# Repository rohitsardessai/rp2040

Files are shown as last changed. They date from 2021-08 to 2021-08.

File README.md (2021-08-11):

# RP2040 Breakout board

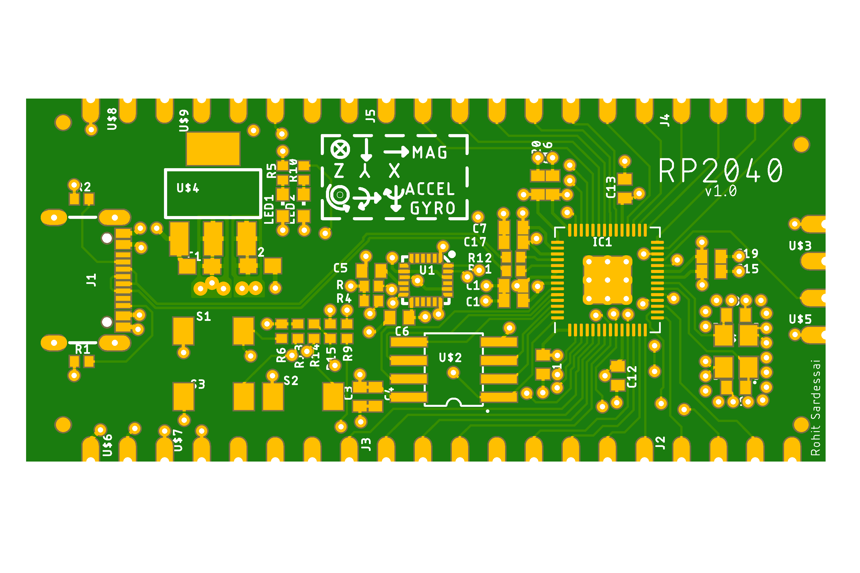
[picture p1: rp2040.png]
Board Preview


Breakout board for the RP2040 microcontroller with minimal circuitry.
The repository contains Eagle board files and libraries.

Features:
- 4 Layer board stackup (sig-gnd-pwr-sig)
- 55mm x 25mm
- RP2040
- USB-C interface (90 Ohm differential impedance)
- MPU9250 9 DoF IMU
- User button and LED
- Castellated pads

This board was made by referring to Philip Salmony's wonderful [YouTube channel](https://www.youtube.com/c/PhilS94/videos) . I highly recommend it.
Sparkfun's open source designs also helped a lot.

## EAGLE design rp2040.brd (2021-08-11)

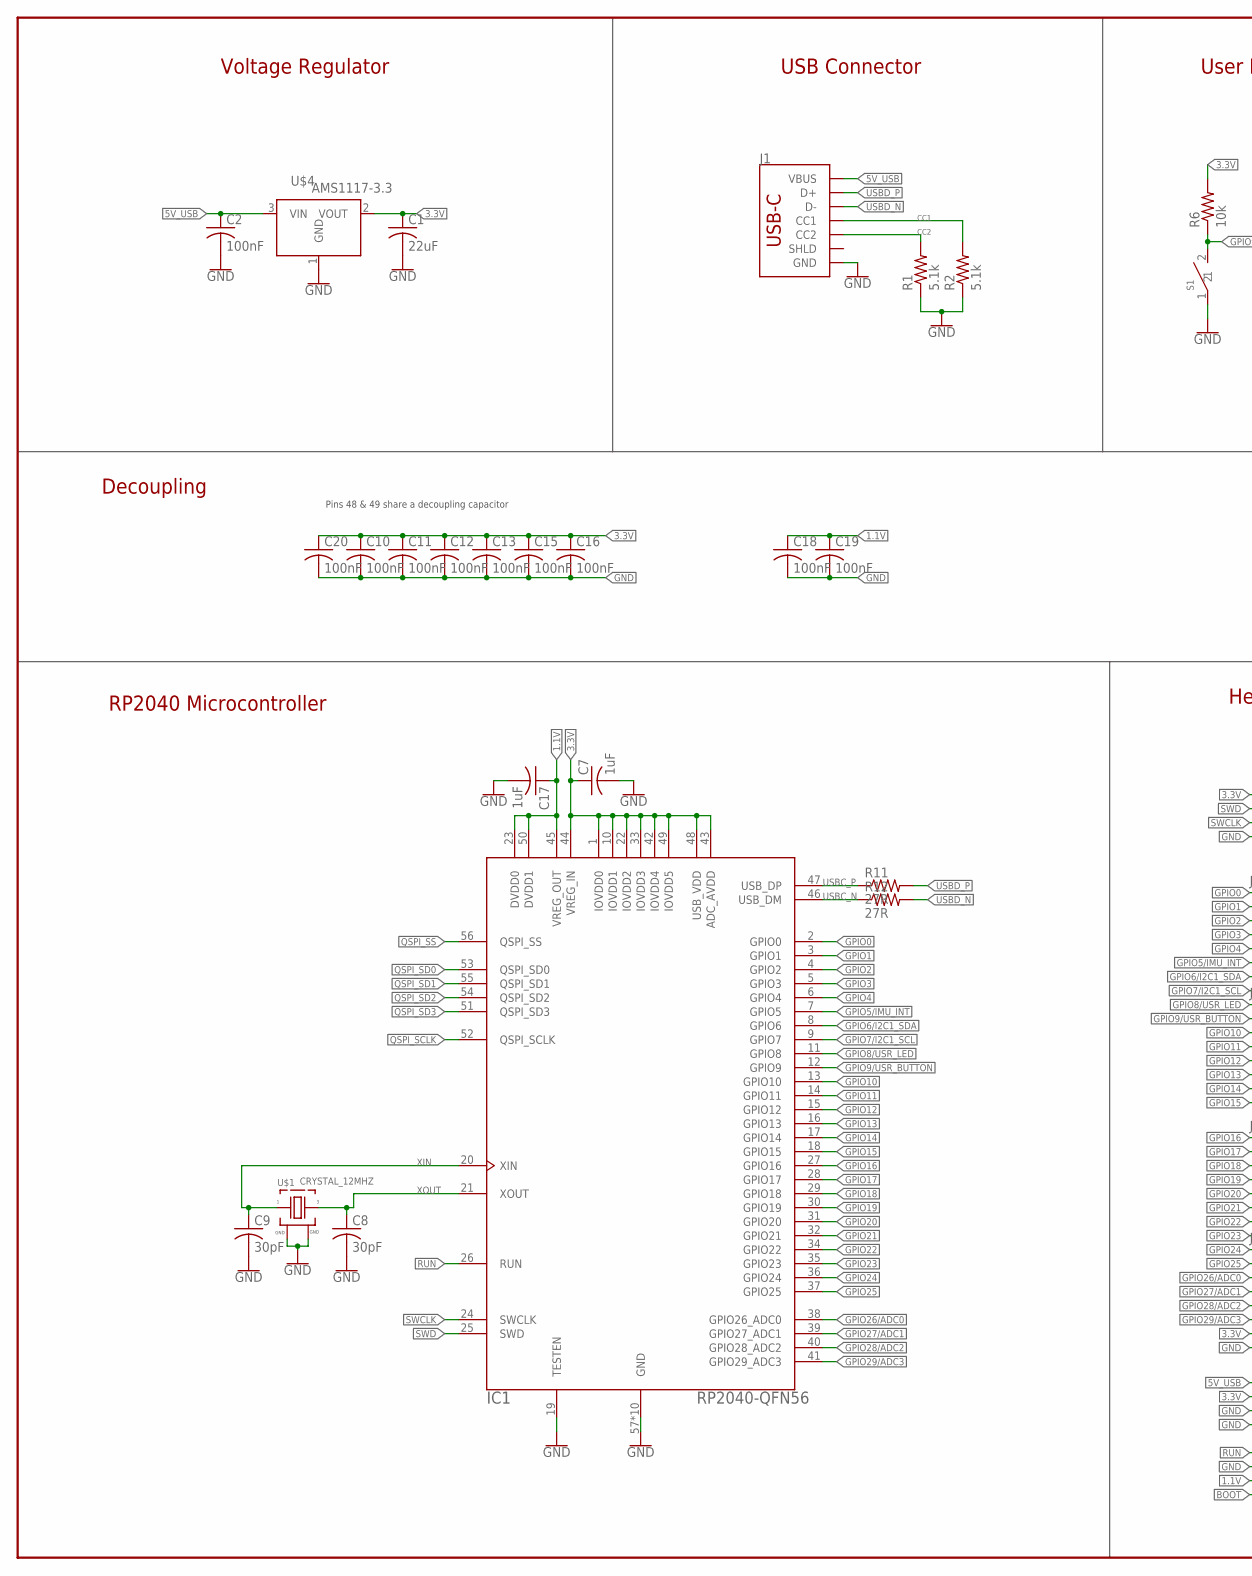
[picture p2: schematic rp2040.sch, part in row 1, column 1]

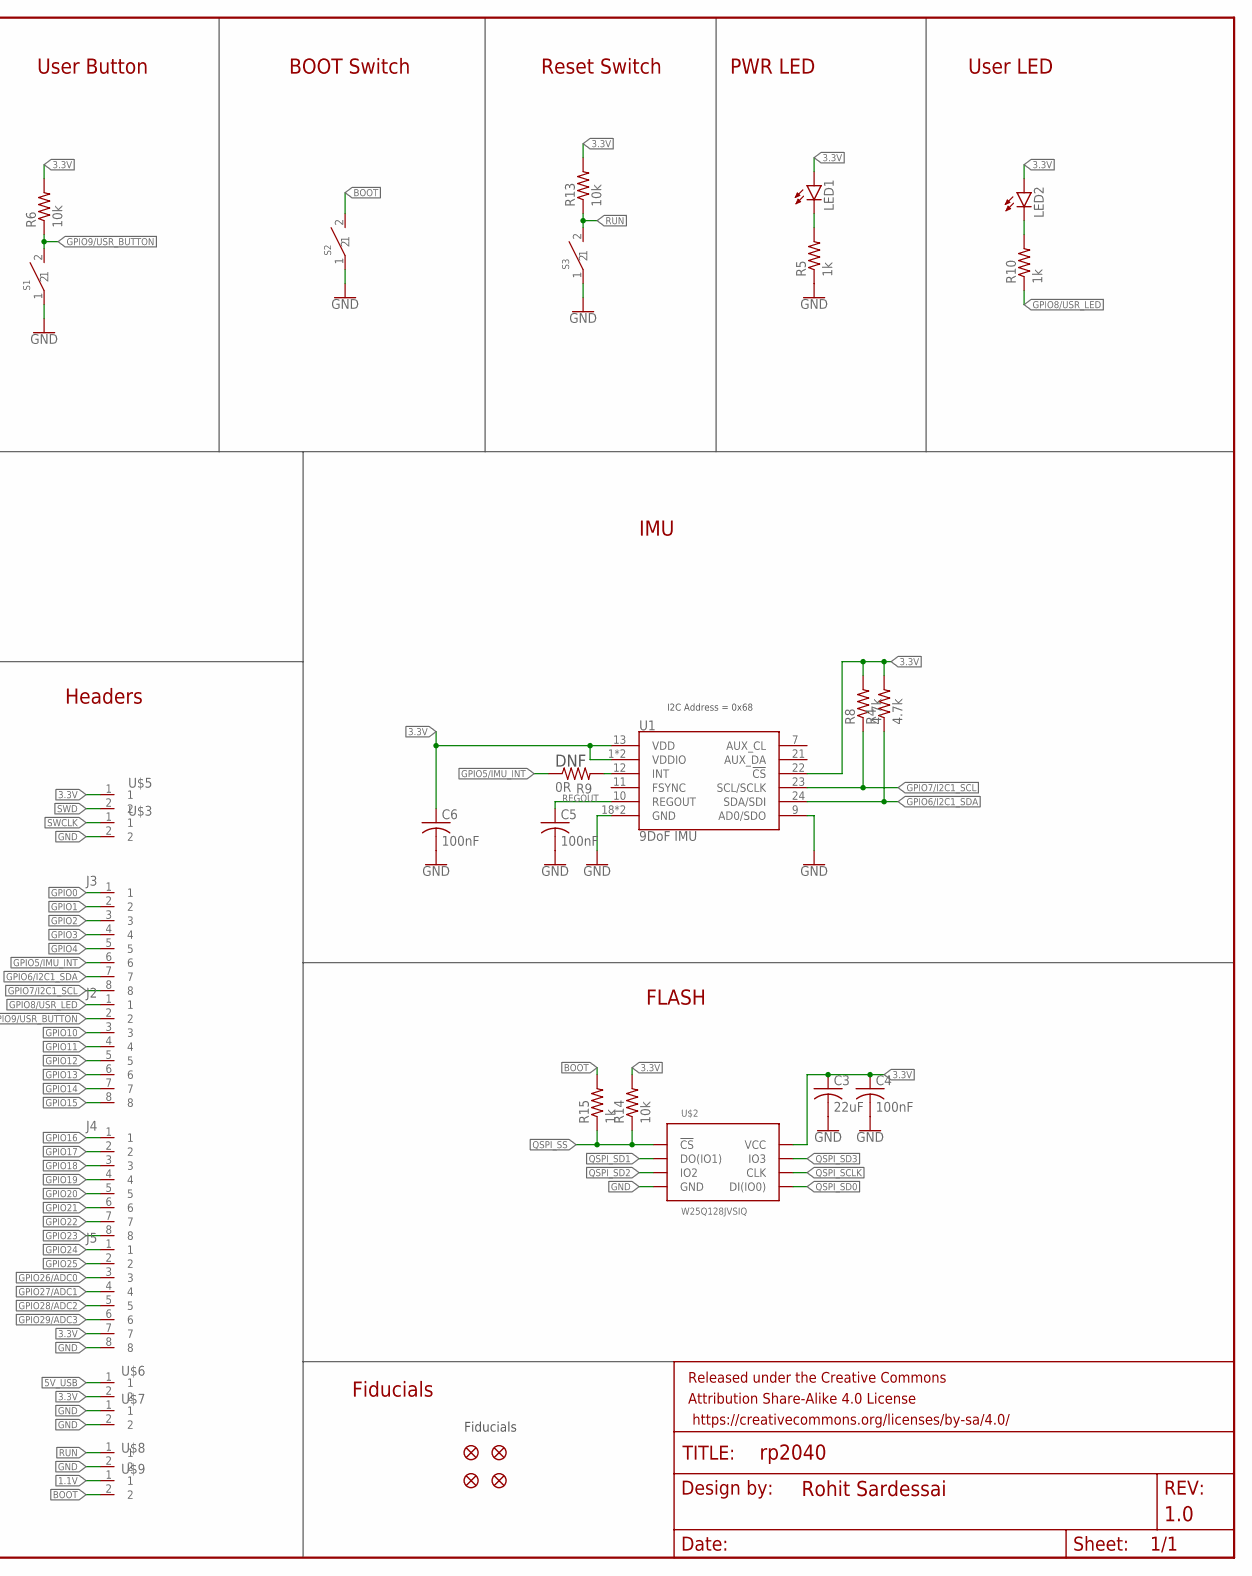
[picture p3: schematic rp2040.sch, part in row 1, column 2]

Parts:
C1: 22uF; C0603
C2: 100nF; C0603
C3: 22uF; C0402
C4, C5, C6, C10, C11, C12, C13, C15, C16, C18, C19, C20: 100nF; C0402
C7, C17: 1uF; C0402
C8, C9: 30pF; C0402
FD1, FD2, FD3, FD4: FIDUCIAL1X2; FIDUCIAL-1X2
FRAME1: FRAME-LEDGERNO_FOOTPRINT; DUMMY
IC1: RP2040-QFN56; RP2040-QFN-56
J1: USB_C_4-LAYER_PADS; USB-C-16P_4LAYER-PADS
J2, J3, J4, J5: 1X6_2.5MM; 1X06_2.5MM
LED1, LED2: LEDCHIPLED_0603; CHIPLED_0603
R1, R2: 5.1k; R0402
R4, R8: 4.7k; R0402
R5, R10, R15: 1k; R0402
R6, R13, R14: 10k; R0402
R9: 0R; R0402
R11, R12: 27R; R0402
S1, S2, S3: TS-1088-AR02016; PUSH_SW_SMD
U1: 9DoF IMU; QFN24-3X3
U$1: CRYSTAL_12MHZ
U$2: W25Q128JVSIQ; SOIC8-208MIL
U$3, U$5, U$6, U$7, U$8, U$9: 1X2_2.5MM; 1X02_2.5MM
U$4: AMS1117-3.3; SOT-223

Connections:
1.1V: C17.1, C18.1, C19.1, IC1.23 (DVDD0), IC1.45 (VREG_OUT), IC1.50 (DVDD1), U$9.1
3.3V: C1.1, C3.1, C4.1, C6.1, C7.1, C10.1, C11.1, C12.1, C13.1, C15.1, C16.1, C20.1, IC1.1 (IOVDD0), IC1.10 (IOVDD1), IC1.22 (IOVDD2), IC1.33 (IOVDD3), IC1.42 (IOVDD4), IC1.43 (ADC_AVDD), IC1.44 (VREG_IN), IC1.48 (USB_VDD), IC1.49 (IOVDD5), J5.7, LED1.A, LED2.A, R4.2, R6.2, R8.2, R13.2, R14.2, U1.1 (VDDIO), U1.8 (VDDIO), U1.13 (VDD), U1.22 (!CS), U$2.8 (VCC), U$4.2 (VOUT), U$5.1, U$6.2
5V_USB: C2.1, J1.VBUS1 (VBUS), J1.VBUS2 (VBUS), U$4.3 (VIN), U$6.1
BOOT: R15.2, S2.2, U$9.2
CC1: J1.A5 (CC1), R2.2
CC2: J1.B5 (CC2), R1.2
GND: C1.2, C2.2, C3.2, C4.2, C5.2, C6.2, C7.2, C8.2, C9.2, C10.2, C11.2, C12.2, C13.2, C15.2, C16.2, C17.2, C18.2, C19.2, C20.2, IC1.19 (TESTEN), IC1.57 (GND), IC1.58 (GND), IC1.59 (GND), IC1.60 (GND), IC1.61 (GND), IC1.62 (GND), IC1.63 (GND), IC1.64 (GND), IC1.65 (GND), IC1.66 (GND), J1.GND, J1.GND2 (GND), J5.8, R1.1, R2.1, R5.1, S1.1, S2.1, S3.1, U1.9 (AD0/SDO), U1.18 (GND), U1.20 (GND), U$1.2 (GND), U$1.4 (GND), U$2.4 (GND), U$3.2, U$4.1 (GND), U$7.1, U$7.2, U$8.2
GPIO0: IC1.2 (GPIO0), J3.1
GPIO1: IC1.3 (GPIO1), J3.2
GPIO2: IC1.4 (GPIO2), J3.3
GPIO3: IC1.5 (GPIO3), J3.4
GPIO4: IC1.6 (GPIO4), J3.5
GPIO5/IMU_INT: IC1.7 (GPIO5), J3.6, R9.1
GPIO6/I2C1_SDA: IC1.8 (GPIO6), J3.7, R4.1, U1.24 (SDA/SDI)
GPIO7/I2C1_SCL: IC1.9 (GPIO7), J3.8, R8.1, U1.23 (SCL/SCLK)
GPIO8/USR_LED: IC1.11 (GPIO8), J2.1, R10.1
GPIO9/USR_BUTTON: IC1.12 (GPIO9), J2.2, R6.1, S1.2
GPIO10: IC1.13 (GPIO10), J2.3
GPIO11: IC1.14 (GPIO11), J2.4
GPIO12: IC1.15 (GPIO12), J2.5
GPIO13: IC1.16 (GPIO13), J2.6
GPIO14: IC1.17 (GPIO14), J2.7
GPIO15: IC1.18 (GPIO15), J2.8
GPIO16: IC1.27 (GPIO16), J4.1
GPIO17: IC1.28 (GPIO17), J4.2
GPIO18: IC1.29 (GPIO18), J4.3
GPIO19: IC1.30 (GPIO19), J4.4
GPIO20: IC1.31 (GPIO20), J4.5
GPIO21: IC1.32 (GPIO21), J4.6
GPIO22: IC1.34 (GPIO22), J4.7
GPIO23: IC1.35 (GPIO23), J4.8
GPIO24: IC1.36 (GPIO24), J5.1
GPIO25: IC1.37 (GPIO25), J5.2
GPIO26/ADC0: IC1.38 (GPIO26_ADC0), J5.3
GPIO27/ADC1: IC1.39 (GPIO27_ADC1), J5.4
GPIO28/ADC2: IC1.40 (GPIO28_ADC2), J5.5
GPIO29/ADC3: IC1.41 (GPIO29_ADC3), J5.6
unnamed: LED1.C, R5.2
unnamed: R9.2, U1.12 (INT)
unnamed: LED2.C, R10.2
QSPI_SCLK: IC1.52 (QSPI_SCLK), U$2.6 (CLK)
QSPI_SD0: IC1.53 (QSPI_SD0), U$2.5 (DI(IO0))
QSPI_SD1: IC1.55 (QSPI_SD1), U$2.2 (DO(IO1))
QSPI_SD2: IC1.54 (QSPI_SD2), U$2.3 (IO2)
QSPI_SD3: IC1.51 (QSPI_SD3), U$2.7 (IO3)
QSPI_SS: IC1.56 (QSPI_SS), R14.1, R15.1, U$2.1 (!CS)
REGOUT: C5.1, U1.10 (REGOUT)
RUN: IC1.26 (RUN), R13.1, S3.2, U$8.1
SWCLK: IC1.24 (SWCLK), U$3.1
SWD: IC1.25 (SWD), U$5.2
USBC_N: IC1.46 (USB_DM), R12.1
USBC_P: IC1.47 (USB_DP), R11.1
USBD_N: J1.A7 (D-), J1.B7 (D-), R12.2
USBD_P: J1.A6 (D+), J1.B6 (D+), R11.2
XIN: C9.1, IC1.20 (XIN), U$1.1
XOUT: C8.1, IC1.21 (XOUT), U$1.3

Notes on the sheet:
Fiducials
DNF
I2C Address = 0x68
Voltage Regulator
USB Connector
User Button
BOOT Switch
PWR LED
User LED
IMU
FLASH
RP2040 Microcontroller
Decoupling
Reset Switch
Headers
Pins 48 & 49 share a decoupling capacitor

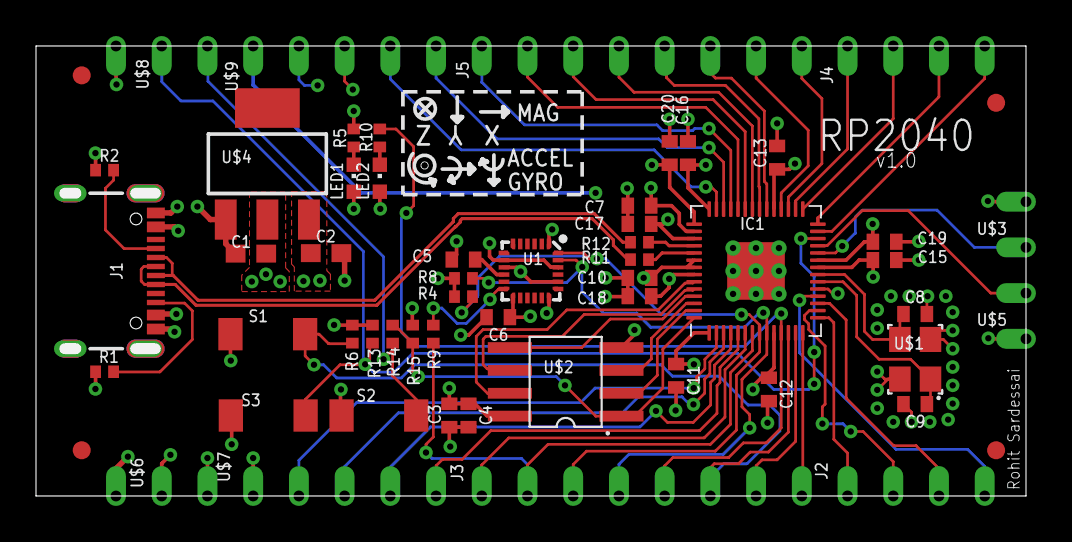
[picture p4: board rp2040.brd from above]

Board: 4 copper layers, 55.0 x 25.0 mm, 58 parts (0 on the bottom side), 56 nets.

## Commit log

2021-08-09 initial board, without final silkscreen
    [rp2040.brd, rp2040.sch]
2021-08-11 added bottom silk
    [rp2040.brd]
2021-08-11 added top & bottom silk
    [rp2040.brd]
2021-08-11 improved traces, reduced vias
    [rp2040.brd]

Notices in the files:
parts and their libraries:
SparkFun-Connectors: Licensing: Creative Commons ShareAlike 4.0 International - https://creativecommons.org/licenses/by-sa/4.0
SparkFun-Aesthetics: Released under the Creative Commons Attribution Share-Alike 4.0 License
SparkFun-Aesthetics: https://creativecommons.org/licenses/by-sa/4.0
